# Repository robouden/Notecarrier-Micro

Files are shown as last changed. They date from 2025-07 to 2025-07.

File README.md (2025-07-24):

# Notecarrier-Micro

This folder contains the design files for the Blues Wireless Notecarrier-Micro, in KiCad 7 format. This is a compact carrier board designed specifically for the Blues Wireless Notecard, providing power management, interface conversion, and mechanical mounting in a minimal form factor.

The Notecarrier-Micro provides essential hardware interfaces including USB-C for programming and power, JST connectors for battery and antenna connections, and standard 0.1" headers for GPIO access. All components are selected for low power consumption and reliability in IoT applications.

## Contents

- This file
 	- `README.md`
- KiCad source files
	- `Notecarrier-Micro.kicad_pcb`
	- `Notecarrier-Micro.kicad_prl`
	- `Notecarrier-Micro.kicad_pro`
	- `Notecarrier-Micro.kicad_sch`
	- `Notecarrier-Micro.kicad_wks`
	- `sym-lib-table`
	- `fp-info-cache`
	- `fp-lib-table`
- Documentation
	- `documentation/*`
- Manufacturing artefacts
	- `manufacturing/*`
- Design references
	- `reference/*`
- Validation artefacts
	- `validation/*`

## Hardware Specifications

### Physical Characteristics
- **Dimensions**: Compact form factor optimized for space-constrained applications
- **Mounting**: Standard mounting holes for secure installation
- **Connectors**: USB-C, JST battery connector, antenna connectors, 0.1" GPIO headers

### Power Management
- **Input Voltage**: USB-C 5V input, Battery input via JST connector
- **Power Regulation**: On-board voltage regulators for stable 3.3V and other required voltages
- **Low Power Design**: Optimized for battery-powered IoT applications

### Interfaces
- **USB-C**: Programming, debugging, and power input
- **Battery Connector**: JST connector for LiPo battery connection
- **Antenna Connectors**: Standard antenna connections for cellular/WiFi
- **GPIO Headers**: 0.1" pitch headers for external sensor/actuator connections
- **I2C/SPI/UART**: Standard communication interfaces exposed via headers

### Compatibility
- **Notecard Support**: Designed specifically for Blues Wireless Notecard modules
- **Module Interface**: M.2 edge connector for Notecard installation
- **External Access**: All Notecard pins accessible via expansion headers

## Manufacturing Files
- **PCB Files**: Complete KiCad manufacturing package in `manufacturing/` directory
- **3D Models**: STEP and WRL files for mechanical integration
- **Assembly**: Pick and place files, BOM, and assembly drawings

## Revision History

| Revision | Date | Author | Description |
|:---:| --- | --- | --- |
| A | 2023-03-31 | H.Raftery  | initial port from OrCAD design files, rev 14 (v2.1). |

### Original OrCad Design File Revision History

| Revision | Date | Author | Description |
|:---:| --- | --- | --- |
| 12 | 25/08/2020 | G.Boschini | - Changed screw with inox version<br/>- Changed pullup resistor of EN pin to 10M |
| 14 | 25/08/2020 | M. Gregis  | - Added LiPO charger<br/>- Changed V+ to VBAT<br/>- removed BOOT signal from J21 header and replaced with GND<br/>- removed AUX5 from J22 header and replaced with VMODEM |

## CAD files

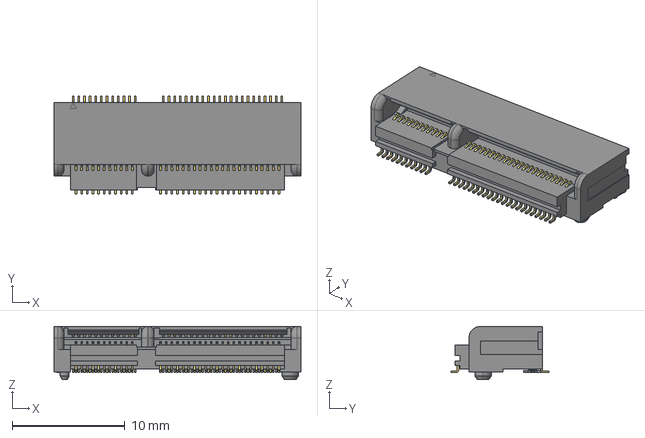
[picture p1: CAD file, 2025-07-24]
J-75-0050-MOS-M2-E.step
21.9 x 8.70 x 4.70 mm

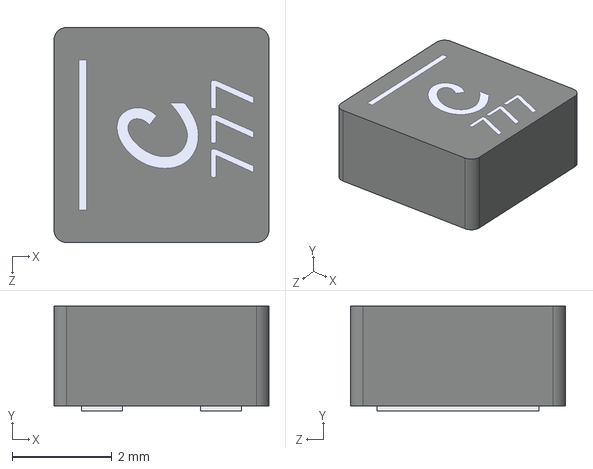
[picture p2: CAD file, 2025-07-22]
Reference/Coilcraft-XFL4020.STEP
4.30 x 2.10 x 4.30 mm

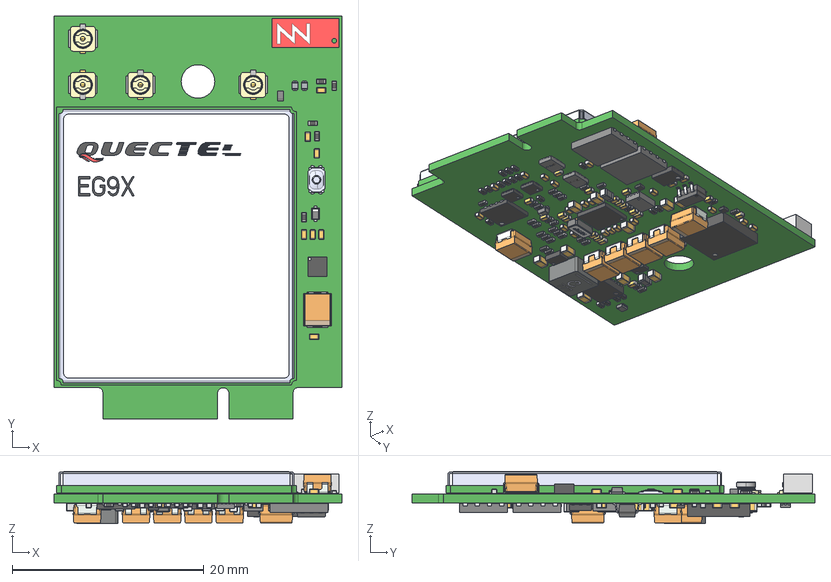
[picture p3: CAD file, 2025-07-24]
Note card-PCB.step
30.0 x 42.0 x 5.42 mm
Board
EG91--3DModel-STEP-418109
EG91--3DModel-STEP-418110
EG91--3DModel-STEP-418111
EG91--3DModel-STEP-418112
EG91--3DModel-STEP-418113
EG91--3DModel-STEP-418114
EG91--3DModel-STEP-418115
EG91--3DModel-STEP-418116
EG91--3DModel-STEP-418117
EG91--3DModel-STEP-418118
EG91--3DModel-STEP-418119
EG91--3DModel-STEP-418120
EG91--3DModel-STEP-418121
EG91--3DModel-STEP-418122
EG91--3DModel-STEP-418123
EG91--3DModel-STEP-418124
EG91--3DModel-STEP-418125
EG91--3DModel-STEP-418126
EG91--3DModel-STEP-418127
EG91--3DModel-STEP-418128
EG91--3DModel-STEP-418129
EG91--3DModel-STEP-418130
EG91--3DModel-STEP-418131
EG91--3DModel-STEP-418132
EG91--3DModel-STEP-418133
EG91--3DModel-STEP-418134
EG91--3DModel-STEP-418135
EG91--3DModel-STEP-418136
EG91--3DModel-STEP-418137
EG91--3DModel-STEP-418138
EG91--3DModel-STEP-418139
EG91--3DModel-STEP-418140
EG91--3DModel-STEP-418141
EG91--3DModel-STEP-418142
EG91--3DModel-STEP-418143
EG91--3DModel-STEP-418144
EG91--3DModel-STEP-418145
EG91--3DModel-STEP-418146
EG91--3DModel-STEP-418147
EG91--3DModel-STEP-418148
EG91--3DModel-STEP-418149
EG91--3DModel-STEP-418150
EG91--3DModel-STEP-418151
EG91--3DModel-STEP-418152
EG91--3DModel-STEP-418153
EG91--3DModel-STEP-418154
EG91--3DModel-STEP-418155
EG91--3DModel-STEP-418156
EG91--3DModel-STEP-418157
EG91--3DModel-STEP-418158
EG91--3DModel-STEP-418159
EG91--3DModel-STEP-418160
EG91--3DModel-STEP-418161
EG91--3DModel-STEP-418162
EG91--3DModel-STEP-418163
EG91--3DModel-STEP-418164
EG91--3DModel-STEP-418165
EG91--3DModel-STEP-418166
EG91--3DModel-STEP-418167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

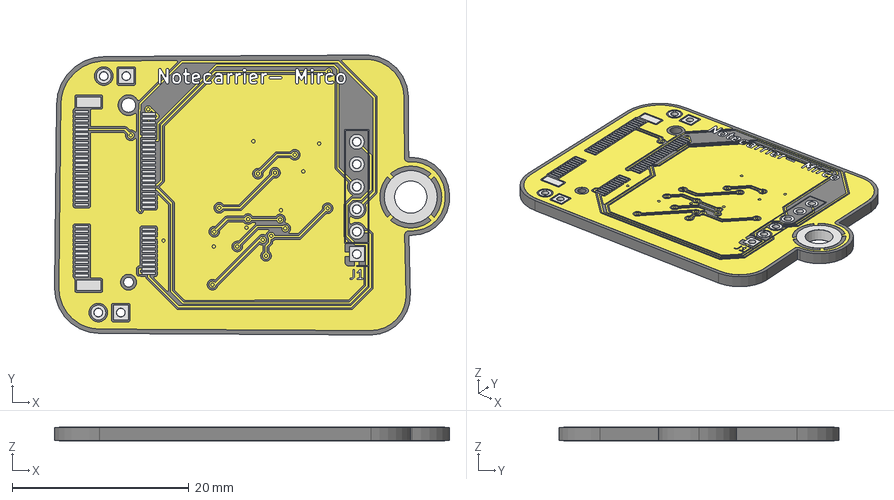
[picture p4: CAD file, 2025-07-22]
Notecarrier-Micro.step
44.6 x 31.6 x 1.63 mm
Notecarrier-Micro_copper
Notecarrier-Micro_pad
Notecarrier-Micro_via
Notecarrier-Micro_silkscreen
Notecarrier-Micro_PCB

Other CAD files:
Notecarrier- Mirco.FCStd
Notecarrier B.blend
Notecarrier-Micro.stl
Reference/Coilcraft-XFL4020.stl

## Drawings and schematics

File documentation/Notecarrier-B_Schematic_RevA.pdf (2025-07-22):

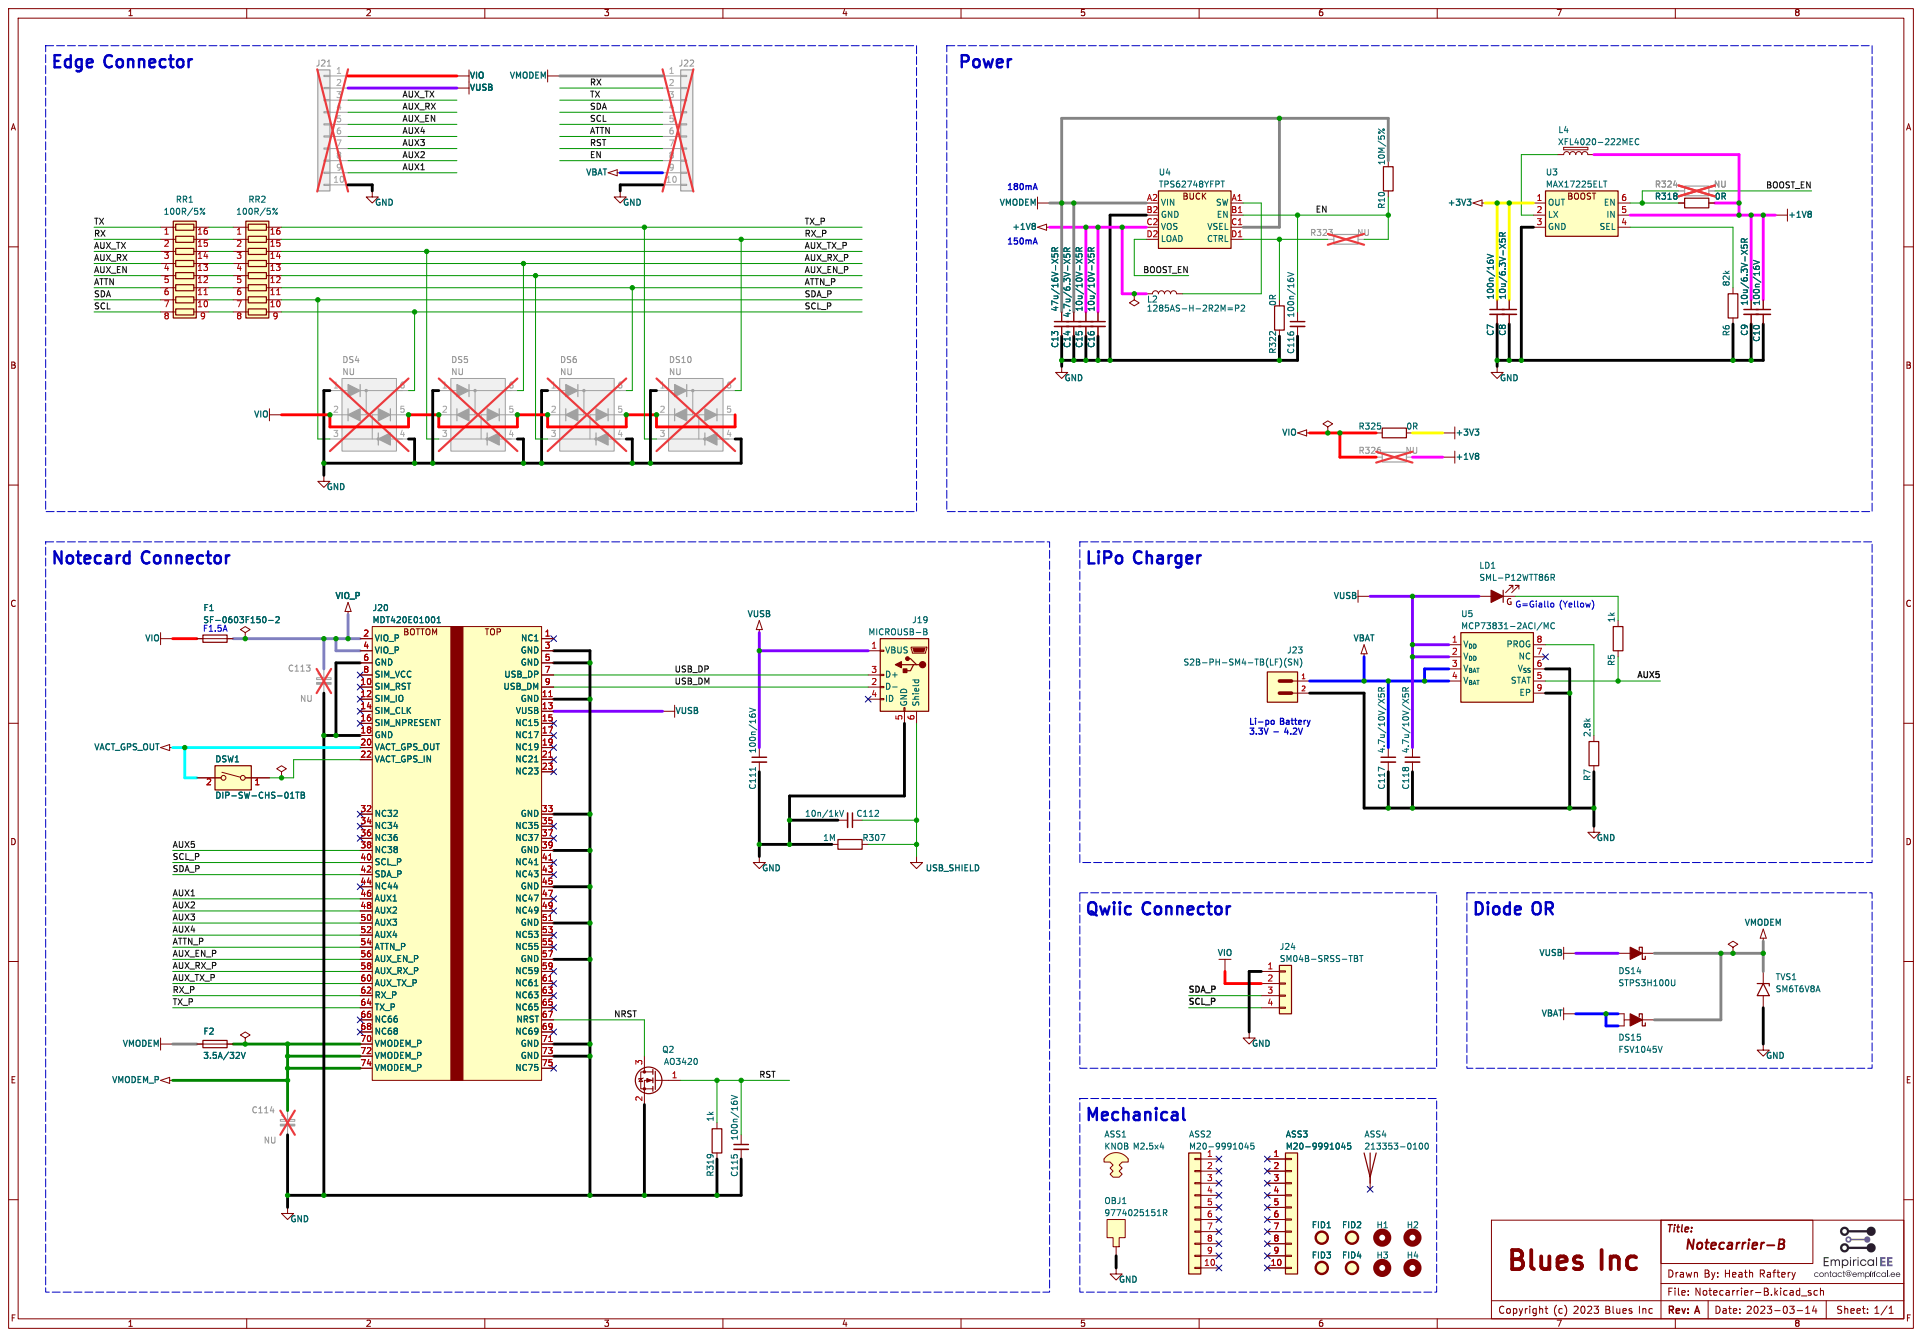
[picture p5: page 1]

2 3 Q2AO3420 GND C111 100n/16V GND C115 100n/16V R319 1k BOTTOM TOP NC1 1 SIM_RST 10 GND 11 SIM_IO 12 VUSB 13 SIM_CLK 14 NC15 15 SIM_NPRESENT 16 NC17 17 GND 18 NC19 19 VIO_P 2 VACT_GPS_OUT 20 NC21 21 VACT_GPS_IN 22 NC23 23 GND 3 NC32 32 GND 33 NC34 34 NC35 35 NC36 36 NC37 37 NC38 38 GND 39 VIO_P 4 SCL_P 40 NC41 41 SDA_P 42 NC43 43 NC44 44 GND 45 AUX1 46 NC47 47 AUX2 48 NC49 49 GND 5 AUX3 50 GND 51 AUX4 52 NC53 53 ATTN_P 54 NC55 55 AUX_EN_P 56 GND 57 AUX_RX_P 58 NC59 59 GND 6 AUX_TX_P 60 NC61 61 RX_P 62 NC63 63 TX_P 64 NC65 65 NC66 66 NRST 67 NC68 68 NC69 69 USB_DP 7 VMODEM_P 70 GND 71 VMODEM_P 72 GND 73 VMODEM_P 74 NC75 75 SIM_VCC 8 USB_DM 9

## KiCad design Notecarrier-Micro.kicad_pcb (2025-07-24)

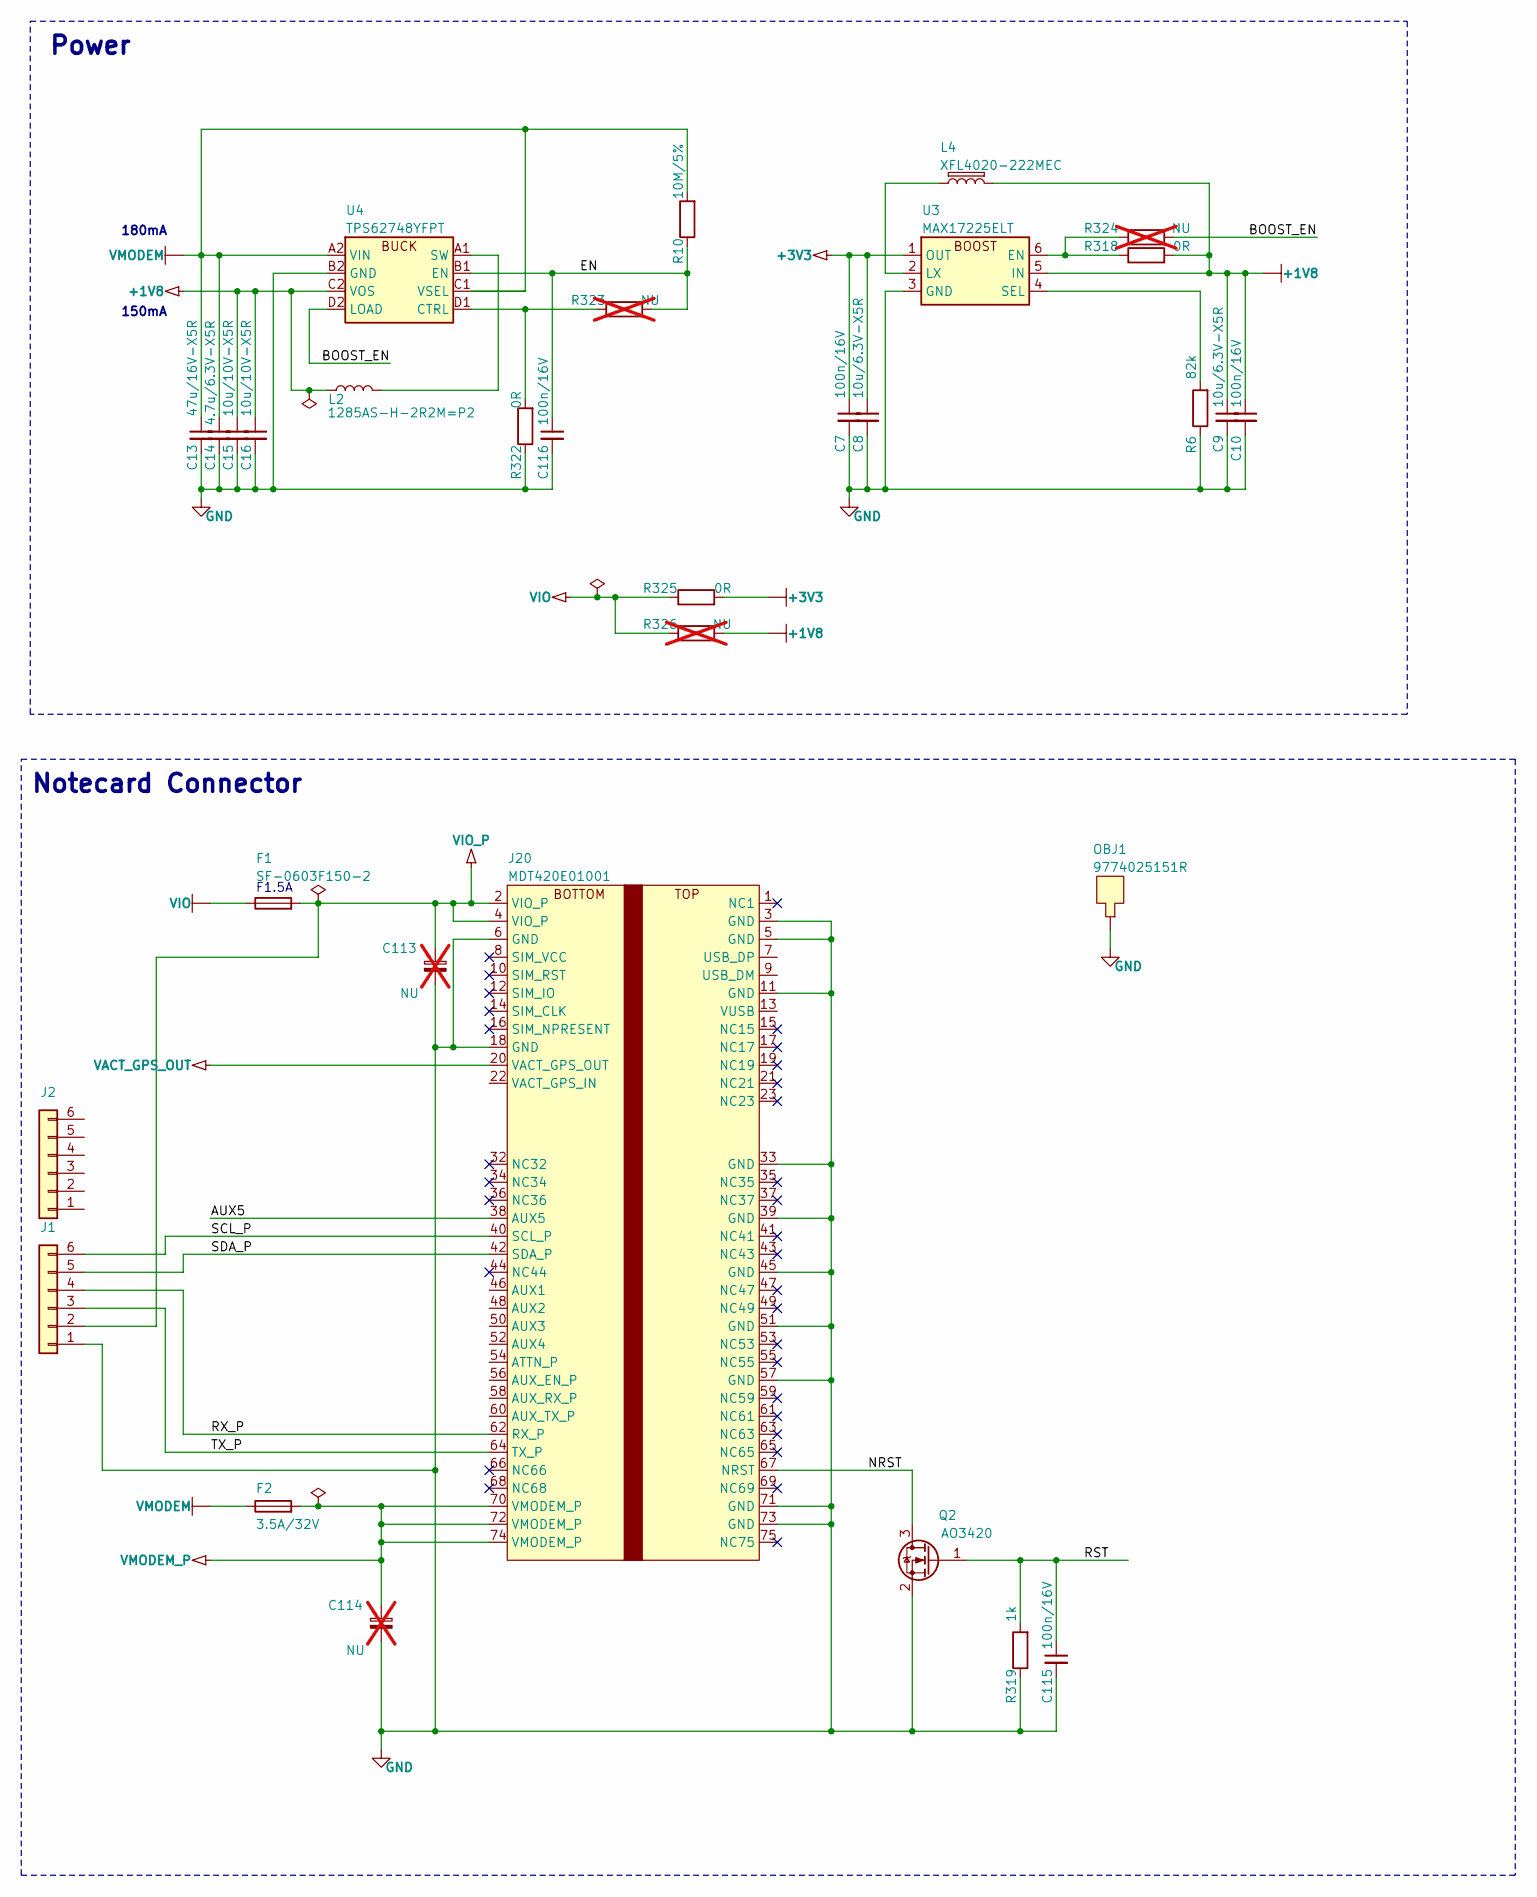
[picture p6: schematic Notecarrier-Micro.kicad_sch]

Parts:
C7, C10, C115, C116: 100n/16V; CS-C-0402_NO-FILL
C8, C9: 10u/6.3V-X5R; CS-C-0402_NO-FILL
C13: 47u/16V-X5R; CS-C-1206
C14: 4.7u/6.3V-X5R; CS-C-0402_NO-FILL
C15, C16: 10u/10V-X5R; CS-C-0603
C113: NU; CS-T-A; MPN F930J107KAA; not fitted
C114: NU; CS-T-B; MPN F930J227KBA; not fitted
F1: SF-0603F150-2; FS-0603; MPN SF-0603F150-2
F2: 3.5A/32V; FS-0603; MPN 0603SFV350F/32-2
J1, J2: Conn_01x06; PinHeader_1x06_P2.54mm_Vertical
J20: MDT420E01001; J-75-0050-MOS-M2-E
L2: 1285AS-H-2R2M=P2; LS-0806; MPN 1285AS-H-2R2M=P2
L4: XFL4020-222MEC; LS-XFL4020; MPN XFL4020-222MEC
OBJ1: 9774025151R; DIST-WASMSIM0250
Q2: AO3420; SOT23_NO-FILL
R6: 82k; RS-0402_NO-FILL
R10: 10M/5%; RS-0402_NO-FILL
R318, R322, R325: 0R; RS-0402_NO-FILL
R319: 1k; RS-0402_NO-FILL
R323, R324, R326: NU; RS-0402_NO-FILL; not fitted
U3: MAX17225ELT; WDFN6-0200X0200; MPN MAX17225ELT+T
U4: TPS62748YFPT; XFBGA8; MPN TPS62748YFPT

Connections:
+1V8: C9.1, C10.1, C15.1, C16.1, L2.2, L4.2, R318.2, R326.2, U3.5 (IN), U4.C2 (VOS)
+3V3: C7.1, C8.1, R325.2, U3.1 (OUT)
/AUX5: J20.38 (AUX5)
/BOOST_EN: R324.2, U4.D2 (LOAD)
/EN: C116.1, R10.1, R323.2, U4.B1 (EN)
/NRST: J20.67 (NRST), Q2.3 (D)
/RST: C115.1, Q2.1 (G), R319.2
/RX_P: J1.4, J20.62 (RX_P)
/SCL_P: J1.6, J20.40 (SCL_P)
/SDA_P: J1.5, J20.42 (SDA_P)
/TX_P: J1.3, J20.64 (TX_P)
GND: C7.2, C8.2, C9.2, C10.2, C13.2, C14.2, C15.2, C16.2, C113.2, C114.2, C115.2, C116.2, J1.1, J20.3 (GND), J20.5 (GND), J20.6 (GND), J20.11 (GND), J20.18 (GND), J20.33 (GND), J20.39 (GND), J20.45 (GND), J20.51 (GND), J20.57 (GND), J20.71 (GND), J20.73 (GND), OBJ1.1, Q2.2 (S), R6.1, R319.1, R322.1, U3.3 (GND), U4.B2 (GND)
unnamed: R318.1, R324.1, U3.6 (EN)
unnamed: L4.1, U3.2 (LX)
unnamed: R6.2, U3.4 (SEL)
unnamed: R322.2, R323.1, U4.D1 (CTRL)
unnamed: L2.1, U4.A1 (SW)
VACT_GPS_OUT: J20.20 (VACT_GPS_OUT)
VIO: F1.1, R325.1, R326.1
VIO_P: C113.1, F1.2, J1.2, J20.2 (VIO_P), J20.4 (VIO_P)
VMODEM: C13.1, C14.1, F2.1, R10.2, U4.A2 (VIN), U4.C1 (VSEL)
VMODEM_P: C114.1, F2.2, J20.70 (VMODEM_P), J20.72 (VMODEM_P), J20.74 (VMODEM_P)

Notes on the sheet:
150mA
180mA
F1.5A
Notecard Connector
Power

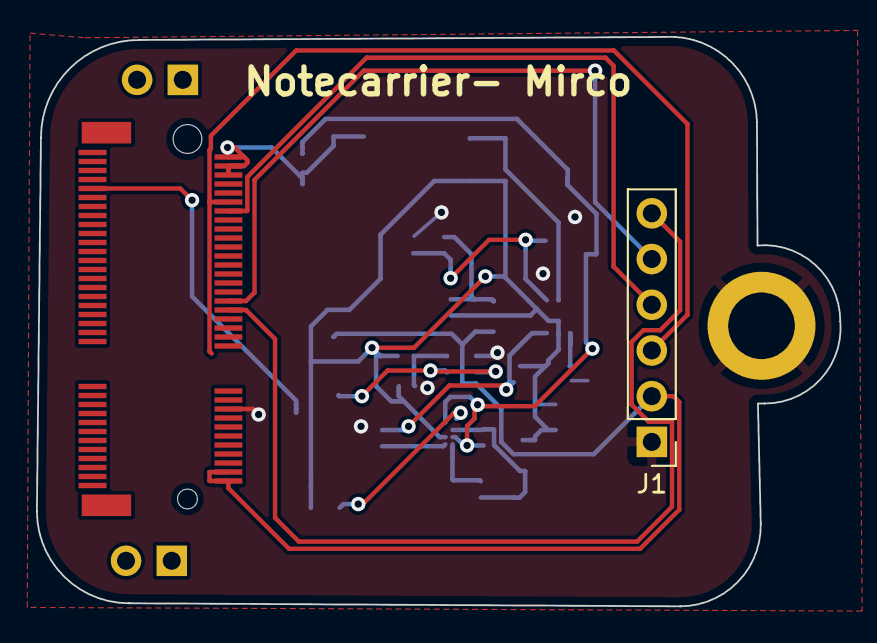
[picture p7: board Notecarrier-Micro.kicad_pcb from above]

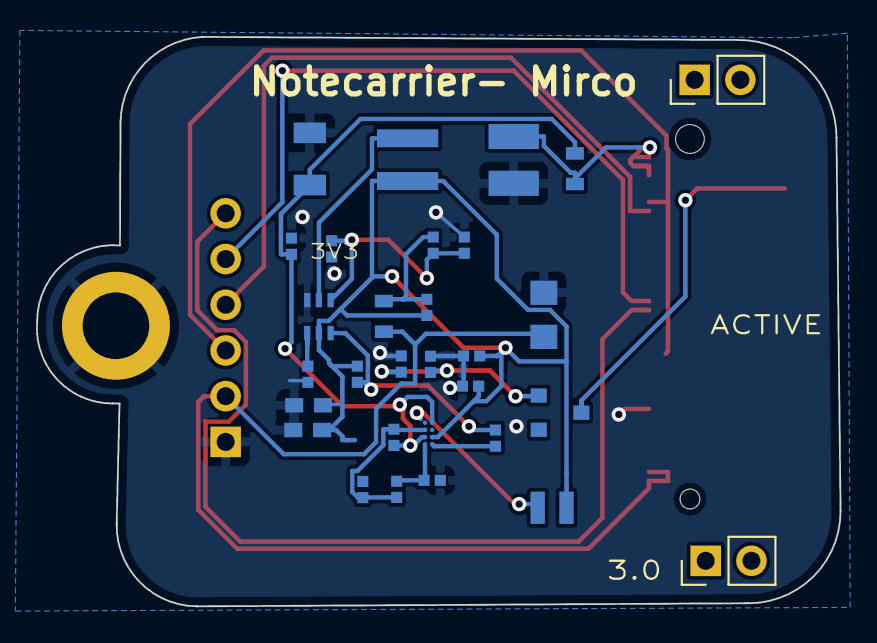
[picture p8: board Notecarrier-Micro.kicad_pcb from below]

Board: 2 copper layers, 44.6 x 31.6 mm, 33 parts (30 on the bottom side), 20 nets.

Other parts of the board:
Extra_pin_1, Extra_pin_2: PinHeader_1x02_P2.54mm_Vertical

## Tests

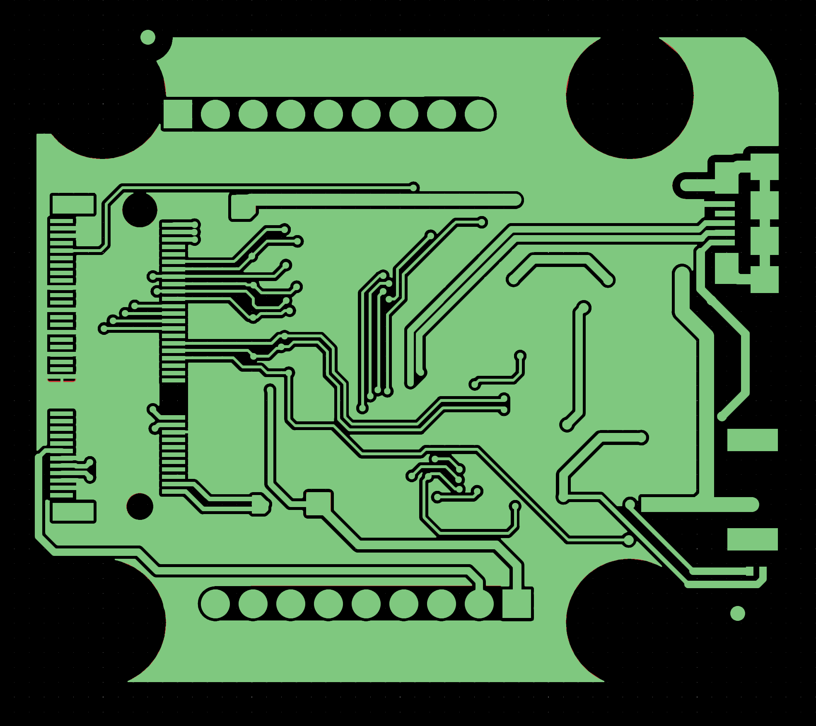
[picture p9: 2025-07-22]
validation/orig/F_Cu-KiCad_top.png

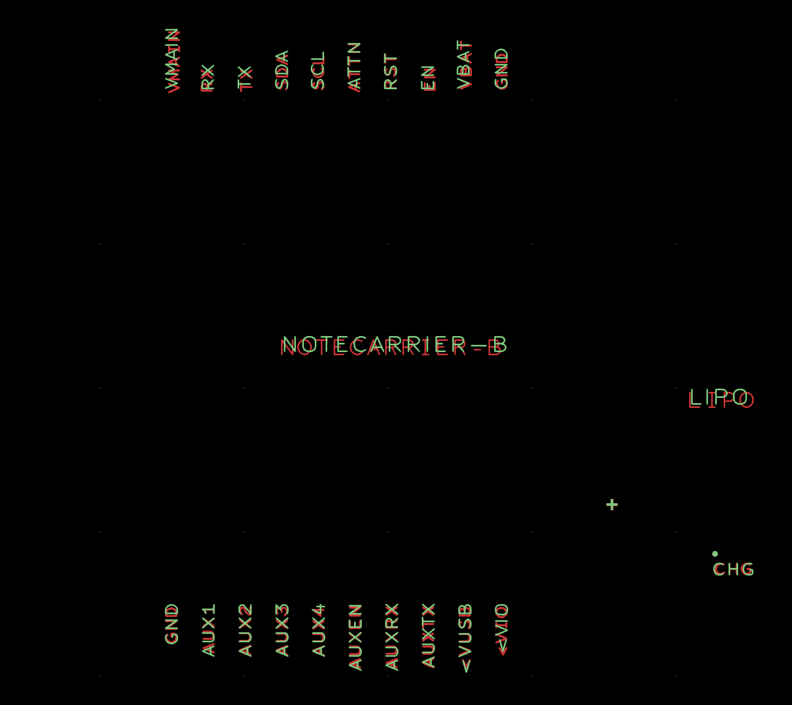
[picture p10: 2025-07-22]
validation/orig/F_Silkscreen-KiCad_top.png

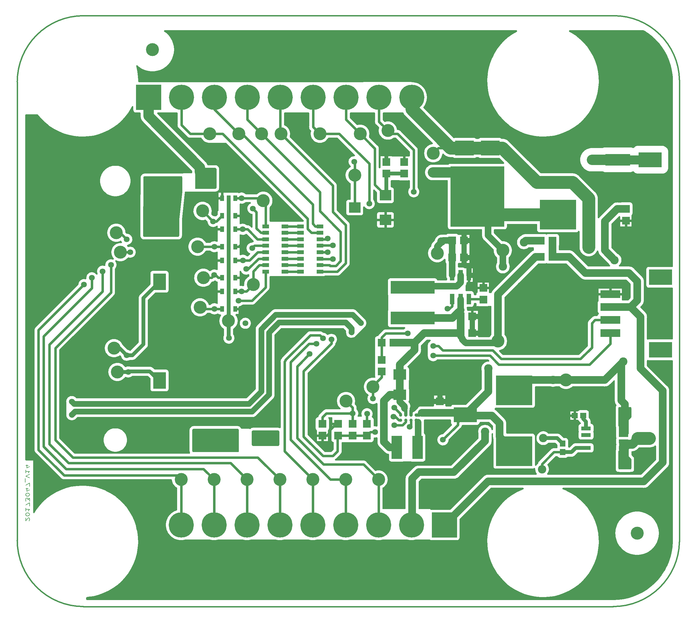
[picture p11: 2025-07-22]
validation/B_Cu-KiCad.png

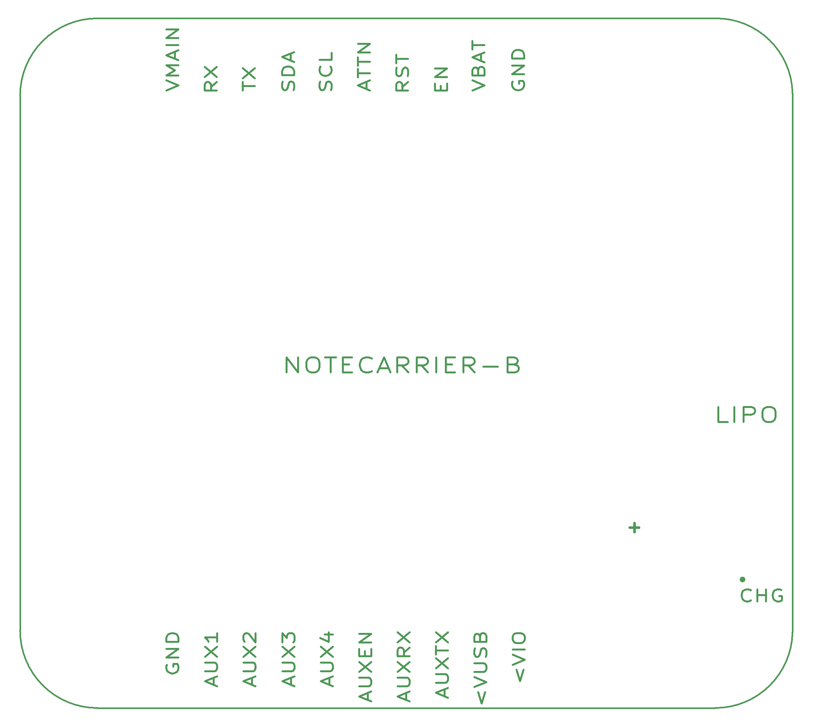
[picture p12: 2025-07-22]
validation/F_Silkscreen-KiCad.png

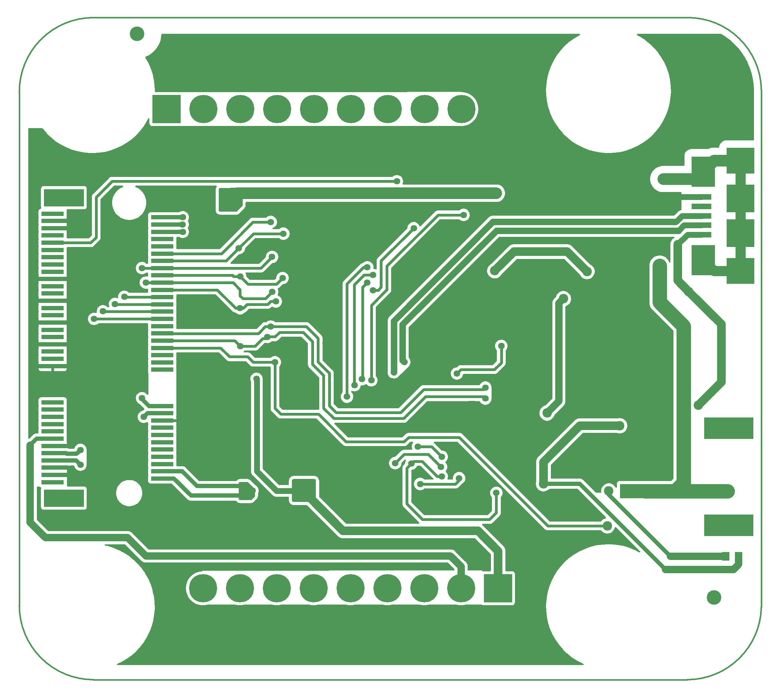
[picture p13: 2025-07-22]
validation/F_Cu-KiCad.png

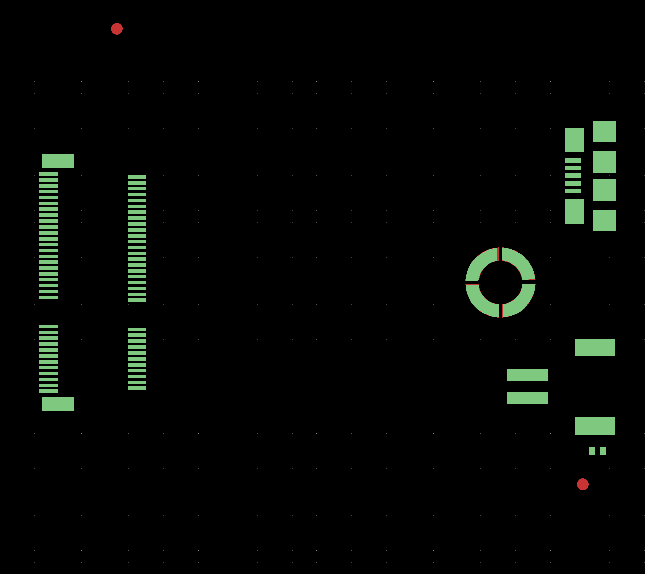
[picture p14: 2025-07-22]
validation/orig/F_Paste-KiCad_top.png

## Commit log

2025-07-24 Small fixes 3D notecard fill
    [Notecarrier B.blend]
2025-07-24 Added 3d model M2 connector
    [J-75-0050-MOS-M2-E.step, Note card-PCB.step, Notecarrier-Micro.kicad_pcb]

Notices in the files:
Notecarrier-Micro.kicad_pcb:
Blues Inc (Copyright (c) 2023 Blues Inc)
